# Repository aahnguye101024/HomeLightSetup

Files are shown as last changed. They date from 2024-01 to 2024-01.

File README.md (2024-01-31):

# HomeLightSetup
This project features 2 boards that work together to turn on strips of SK9822 wirelessly and either turn on them using my iphone with shortcuts through wifi or through the main board through a cap touch interface. The main board having an esp32 pico d4 with an antenna for WiFi access, a cap touch ic, and additions to support a lipo battery. The auxiliary board features an esp32 pico d4 with an antenna to communicate with the main board and a hefty 12V to 5V buck to run lights off of.

# Main Board
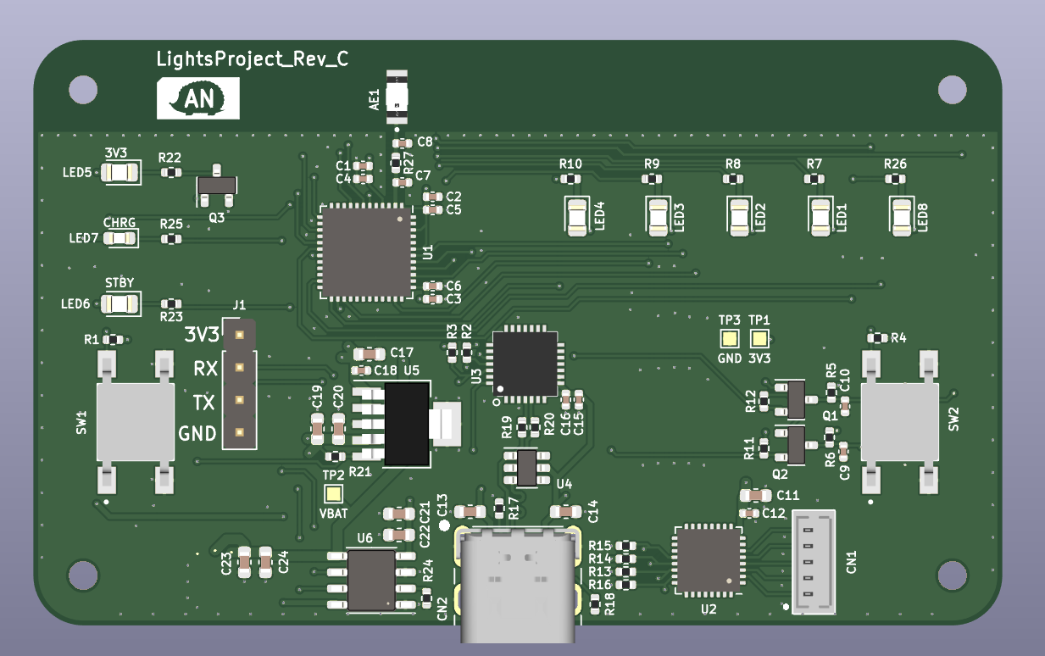
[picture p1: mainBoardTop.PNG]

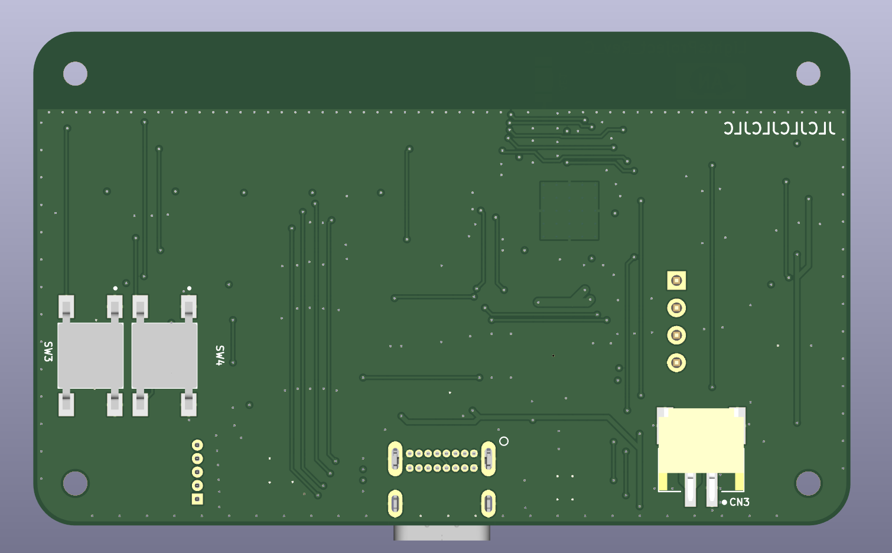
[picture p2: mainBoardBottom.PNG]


# Auxiliary Board
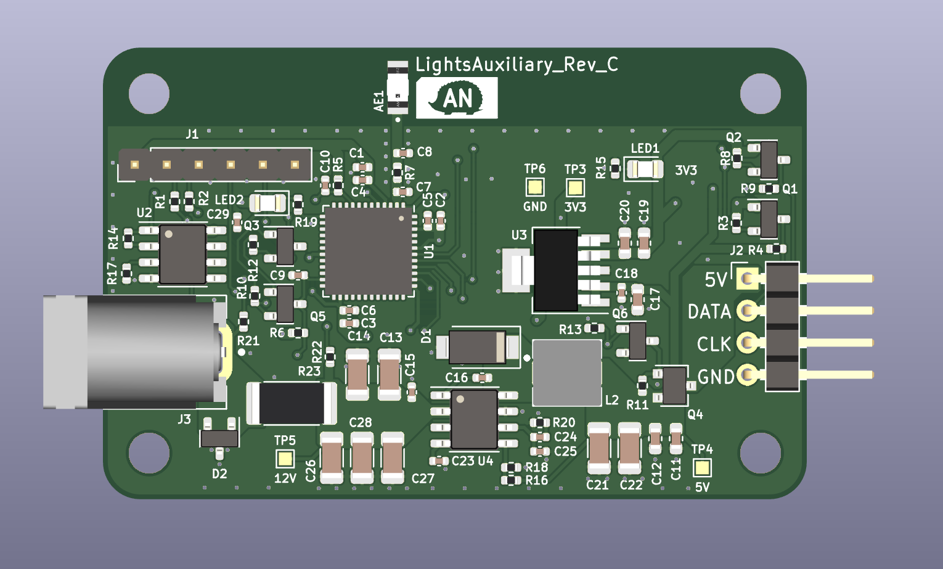
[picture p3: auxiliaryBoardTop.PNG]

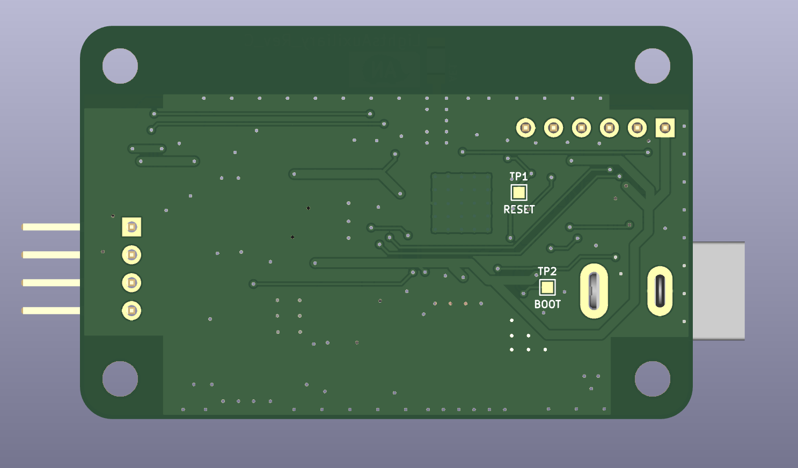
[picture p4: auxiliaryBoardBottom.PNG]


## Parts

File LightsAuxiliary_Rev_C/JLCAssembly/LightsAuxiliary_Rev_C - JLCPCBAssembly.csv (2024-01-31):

Comment | Designator | Footprint | JLCPCB Part #（optional）
2.2uF | C17, C19, C20, | 0603 | C23630
0.1uF | C4, C5, C6, C9, C15, C16, C18, C29, | 0402 | C1525
1uF | C1, C2, C3, C10, | 0402 | C52923
22uF | C13, C14, C26, C27, C28, | 0603 | C59461
47uF | C21, C22, | 1206 | C96123
6.8nF | C23, | 0402 | C1542
4.7nF | C24, | 0402 | C1538
SS54 | D1, | SMA,DO-214AC | C22452
PSM712-LF-T7 | D2, | SOT-23-3 | C32677
SLO0530H6R8MTT | L2, | SMD_5.4x5.2x3mm | C325965
2N7002 | Q1, Q2, Q6, | SOT-23-3 | C8545
MMBT3904 | Q3, Q5, | SOT-23-3 | C20526
AO3401A | Q4, | SOT-23-3L | C15127
0 | R1, R2, R7, | 0402 | C17168
10k | R3, R4, R5, R8, R9, R10, R12, R16, | 0402 | C25744
4.7k | R6, R11, R13, | 0402 | C25900
100k | R14, R17, | 0402 | C25741
330 | R15, R19, | 0402 | C25104
49.9k | R20, | 0402 | C25897
1k | R21, R22, | 0402 | C11702
ESP32-PICO-D4 | U1, | QFN-48_EP_7.0x7.0x0.5P | C193707
LM358DR2G | U2, | SOIC-8_3.9x4.9x1.27P | C7950
TPS54331DR | U4, | SOIC-8_3.9x4.9x1.27P | C9865

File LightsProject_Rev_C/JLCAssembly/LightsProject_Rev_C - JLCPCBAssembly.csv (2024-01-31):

Comment | Designator | Footprint | JLCPCB Part #（optional）
1uF | C1, C2, C3, C10, C15, | 0402 | C52923
0.1uF | C4, C5, C6, C9, C12, C16, C18, | 0402 | C1525
2.2uF | C11, C13, C14, C17, C19, C20, | 0603 | C23630
4.7uF | C21, C22, C23, C24, | 0603 | C19666
19-213/Y2C-CQ2R2L/3T(CY) | LED7, | LED_0603 | C72038
MMBT3904 | Q1, Q2, | SOT-23-3 | C20526
2N7002 | Q3, | SOT-23-3 | C8545
4.7k | R1, R4, R6, R13, R14, R15, R16, | 0402 | C25900
0 | R2, R3, R19, R20, R27, | 0402 | C17168
10k | R5, R11, R12, | 0402 | C25744
330 | R7, R8, R9, R10, R22, R26, | 0402 | C25104
5.1k | R17, R18, | 0402 | C25905
100k | R21, | 0402 | C25741
1.5k | R23, R25, | 0402 | C25867
1.2k | R24, | 0402 | C25862
ESP32-PICO-D4 | U1, | QFN-48_EP_7.0x7.0x0.5P | C193707
CP2102-GMR | U3, | QFN-28_EP_5.0x5.0x0.5P | C6568
SRV05-4-P-T7 | U4, | SOT-23-6L | C85364
TP4056-42-ESOP8 | U6, | ESOP-8_EP_3.9x4.9x1.27P | C16581

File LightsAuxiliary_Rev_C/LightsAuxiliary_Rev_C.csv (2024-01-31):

Source: | C:\Users\AaronN\Desktop\Personal\PersonalProjects\LightsProject\VersionC\LightsAuxiliary_Rev_C\LightsAuxiliary_Rev_C.kicad_sch
Date: | 2/7/2022 12:26:49 AM
Tool: | Eeschema (6.0.0)
Generator: | C:\Program Files\KiCad\bin\scripting\plugins/AaronsFavoriteBOMScript.py
Component Count: | 70
Ref | Qnty | Value | Cmp name | Description | Manufacturer | Part Number
AE1, | 1 | AMCA31-2R450G-S1F-T3 | AMCA31-2R450G-S1F-T3 | RF ANT 2.4GHZ CHIP SOLDER SMD | Abracon LLC | 535-14095-1-ND
C1, C2, C3, C10, | 4 | 1uF | 1uF | CAP CER 1UF 10V X5R 0402 | Samsung Electro-Mechanics | 1276-1076-1-ND
C4, C5, C6, C9, C15, C16, C18, C29, | 8 | 0.1uF | 0.1uF | CAP CER 0.1UF 25V X5R 0402 | Samsung Electro-Mechanics | 1276-1043-1-ND
C11, C12, | 2 | 22uF | 22uF | CAP CER 22UF 10V X5R 0603 | Samsung Electro-Mechanics | 1276-1274-1-ND
C13, C14, C26, C27, C28, | 5 | 22uF_1206 | 22uF_1206 | CAP CER 22UF 25V X5R 1206 | Samsung Electro-Mechanics | 1276-3047-1-ND
C17, C19, C20, | 3 | 2.2uF | 2.2uF | CAP CER 2.2UF 10V X5R 0603 | Samsung Electro-Mechanics | 1276-1085-1-ND
C21, C22, | 2 | 47uF | 47uF | CAP CER 47UF 16V X5R 1206 | Taiyo Yuden | 587-5425-1-ND
C23, | 1 | 6.8nF | 6.8nF | CAP CER 0402 6.8NF 50V X7R 10% | KEMET | 399-C0402C682K5RECAUTOCT-ND
C24, | 1 | 4700pF | 4700pF | CAP CER 4700PF 50V X7R 0402 | YAGEO | 311-1418-1-ND
C25, | 1 | 39pF | 39pF | CAP CER 39PF 50V C0G/NP0 0402 | Murata Electronics | 490-5871-1-ND
D1, | 1 | SS54 | SS54 | JLCPCB 40V 550mV@5A 5A SMA(DO-214AC) Schottky Barrier Diodes (SBD) ROHS | JLCPCB | C22452
D2, | 1 | PSM712-LF-T7 | PSM712-LF-T7 | JLCPCB 19V 13.3V 12V Bi-Directional SOT-23(SOT-23-3) TVS ROHS | JLCPCB | C32677
J1, | 1 | Conn_01x06 | Conn_01x06 | Generic connector, single row, 01x06, script generated (kicad-library-utils/schlib/autogen/connector/)
J2, | 1 | Conn_01x04 | Conn_01x04 | Generic connector, single row, 01x04, script generated (kicad-library-utils/schlib/autogen/connector/)
J3, | 1 | PJ-037AH | PJ-037AH | DC Barrel Jack 2.1mm by 5.50mm R/A | CUI Devices | PJ-037AH
L1, | 1 | LQG15HS2N7S02D | LQG15HS2N7S02D | FIXED IND 2.7NH 800MA 150MOHM SM | Murata Electronics | 490-2615-1-ND
L2, | 1 | SLO0530H6R8MTT | SLO0530H6R8MTT | JLCPCB 4A 6.8uH ±20% 66mΩ SMD Power Inductors ROHS | JLCPCB | C325965
LED1, LED2, | 2 | NCD0805R1 | NCD0805R1 | JLCPCB LED RED DIFFUSED 0805 SMD | Foshan NationStar Optoelectronics | C84256
Q1, Q2, Q6, | 3 | 2N7002 | 2N7002 | JLCPCB MOSFET N-CH 60V 115MA SOT-23 | Changjiang Electronics Tech (CJ) | C8545
Q3, Q5, | 2 | MMBT3904 | MMBT3904 | JLCPCB 0.2W 0.2A NPN 40V SOT-23(SOT-23-3) Bipolar Transistors - BJT ROHS | Changjiang Electronics Tech (CJ) | C20526
Q4, | 1 | AO3401A | AO3401A | JLCPCB 1.4W 0.044Ω 4.3A,10V 30V 1.3V 250uA P Channel 4A SOT-23-3L MOSFETs ROHS | JLCPCB | C15127
R1, R2, R7, | 3 | 0 | 0 | RES 0 OHM JUMPER 1/16W 0402 | Stackpole Electronics Inc | RMCF0402ZT0R00CT-ND
R3, R4, R5, R8, R9, R10, R12, R16, | 8 | 10k | 10k | RES 10K OHM 1% 1/16W 0402 | Stackpole Electronics Inc | RMCF0402FT10K0CT-ND
R6, R11, R13, | 3 | 4.7k | 4.7k | RES 4.7K OHM 1% 1/16W 0402 | Stackpole Electronics Inc | RMCF0402FT4K70CT-ND
R14, R17, | 2 | 100k | 100k | RES SMD 100 KOHM 1% 1/16W 0402 | Delta Electronics/Cyntec | 2037-PFR05S-104-FNHCT-ND
R15, R19, | 2 | 330 | 330 | RES 330 OHM 1% 1/16W 0402 | YAGEO | 311-330LRCT-ND
R18, | 1 | 1.91k | 1.91k | RES 1.91K OHM 1% 1/16W 0402 | Stackpole Electronics Inc | RMCF0402FT1K91CT-ND
R20, | 1 | 49.9k | 49.9k | RES 49.9K OHM 1% 1/16W 0402 | Stackpole Electronics Inc | RMCF0402FT49K9CT-ND
R21, R22, | 2 | 1k | 1k | RES 1K OHM 1% 1/16W 0402 | Stackpole Electronics Inc | RMCF0402FT1K00CT-ND
R23, | 1 | 0.006 | 0.006 | RES 0.006 OHM 1% 1W 2512 | YAGEO | YAG2146CT-ND
U1, | 1 | ESP32-PICO-D4 | ESP32-PICO-D4 |  | Espressif Systems | 1904-1029-1-ND
U2, | 1 | LM358DR2G | LM358DR2G | JLCPCB 0.6 V/us 2 1MHz 3V ~ 32V, ±1.5V ~ 16V 1.5mA General Purpose SOIC-8_150mil Operational Amplifier ROHS | JLCPCB | C7950
U3, | 1 | MCP1826T-3302E_DC | MCP1826T-3302E_DC | IC REG LINEAR 3.3V 1A SOT223-5 | Microchip Technology | Ologic
U4, | 1 | TPS54331DR | TPS54331DR | JLCPCB IC REG BUCK ADJUSTABLE 3A 8SOIC | Texas Instruments | 296-26991-1-ND

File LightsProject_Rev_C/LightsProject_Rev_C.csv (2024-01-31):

Source: | C:\Users\AaronN\Desktop\Personal\PersonalProjects\LightsProject\VersionC\LightsProject_Rev_C\LightsProject_Rev_C.kicad_sch
Date: | 2/7/2022 8:01:38 PM
Tool: | Eeschema (6.0.0)
Generator: | C:\Program Files\KiCad\bin\scripting\plugins/AaronsFavoriteBOMScript.py
Component Count: | 75
Ref | Qnty | Value | Cmp name | Description | Manufacturer | Part Number
AE1, | 1 | AMCA31-2R450G-S1F-T3 | AMCA31-2R450G-S1F-T3 | RF ANT 2.4GHZ CHIP SOLDER SMD | Abracon LLC | 535-14095-1-ND
C1, C2, C3, C10, C15, | 5 | 1uF | 1uF | CAP CER 1UF 10V X5R 0402 | Samsung Electro-Mechanics | 1276-1076-1-ND
C4, C5, C6, C9, C12, C16, C18, | 7 | 0.1uF | 0.1uF | CAP CER 0.1UF 25V X5R 0402 | Samsung Electro-Mechanics | 1276-1043-1-ND
C11, C13, C14, C17, C19, C20, | 6 | 2.2uF | 2.2uF | CAP CER 2.2UF 10V X5R 0603 | Samsung Electro-Mechanics | 1276-1085-1-ND
C21, C22, C23, C24, | 4 | 4.7uF | 4.7uF | CAP CER 4.7UF 16V X5R 0603 | Samsung Electro-Mechanics | 1276-1784-1-ND
CN1, | 1 | 0530470510 | 0530470510 | PICOBLADE VERT CONN HEADER VERT 5POS 1.25MM | Molex | WM1734-ND
CN2, | 1 | 2137160001 | 2137160001 | CONN RCPT USB2.0 TYPE C 24POS RA | Molex | 900-2137160001CT-ND
CN3, | 1 | S2B-PH-SM4-TB(LF)(SN) | S2B-PH-SM4-TB(LF)(SN) | JST PH R/A CONN HEADER SMD R/A 2POS 2MM | JST Sales America Inc. | 455-1749-1-ND
L1, | 1 | LQG15HS2N7S02D | LQG15HS2N7S02D | FIXED IND 2.7NH 800MA 150MOHM SM | Murata Electronics | 490-2615-1-ND
LED1, LED2, LED3, LED4, LED5, LED6, LED8, | 7 | NCD0805R1 | NCD0805R1 | JLCPCB LED RED DIFFUSED 0805 SMD | Foshan NationStar Optoelectronics | C84256
LED7, | 1 | Y2C-CQ2R2L | Y2C-CQ2R2L | JLCPCB LED YELLOW DIFFUSED 0603 SMD | Everlight Elec | C72038
Q1, Q2, | 2 | MMBT3904 | MMBT3904 | JLCPCB 0.2W 0.2A NPN 40V SOT-23(SOT-23-3) Bipolar Transistors - BJT ROHS | Changjiang Electronics Tech (CJ) | C20526
Q3, | 1 | 2N7002 | 2N7002 | JLCPCB MOSFET N-CH 60V 115MA SOT-23 | Changjiang Electronics Tech (CJ) | C8545
R1, R4, R6, R13, R14, R15, R16, | 7 | 4.7k | 4.7k | RES 4.7K OHM 1% 1/16W 0402 | Stackpole Electronics Inc | RMCF0402FT4K70CT-ND
R2, R3, R19, R20, R27, | 5 | 0 | 0 | RES 0 OHM JUMPER 1/16W 0402 | Stackpole Electronics Inc | RMCF0402ZT0R00CT-ND
R5, R11, R12, | 3 | 10k | 10k | RES 10K OHM 1% 1/16W 0402 | Stackpole Electronics Inc | RMCF0402FT10K0CT-ND
R7, R8, R9, R10, R22, R26, | 6 | 330 | 330 | RES 330 OHM 1% 1/16W 0402 | YAGEO | 311-330LRCT-ND
R17, R18, | 2 | 5.1k | 5.1k | RES 5.1K OHM 1% 1/16W 0402 | YAGEO | 311-5.10KLRCT-ND
R21, | 1 | 100k | 100k | RES SMD 100 KOHM 1% 1/16W 0402 | Delta Electronics/Cyntec | 2037-PFR05S-104-FNHCT-ND
R23, R25, | 2 | 1.5k | 1.5k | RES 1.5K OHM 1% 1/16W 0402 | Stackpole Electronics Inc | RMCF0402FT1K50CT-ND
R24, | 1 | 1.2k | 1.2k | RES SMD 1.2K OHM 1% 1/16W 0402 | YAGEO | YAG3447CT-ND
SW1, SW2, SW3, SW4, | 4 | FSM2JSMAA | FSM2JSMAA | SMD Momentary PushButton | FSM2JSMAA | 450-3355-ND
U1, | 1 | ESP32-PICO-D4 | ESP32-PICO-D4 |  | Espressif Systems | 1904-1029-1-ND
U2, | 1 | CAP1114-1-EZK-TR | CAP1114-1-EZK-TR | IC TOUCH SENSOR/LED DRVR 32VQFN | Ologic | Ologic
U3, | 1 | CP2102-GMR | CP2102-GMR | JLCPCB IC USB-TO-UART BRIDGE 28VQFN | CP2102-GMR | IC USB-TO-UART BRIDGE 28VQFN
U4, | 1 | SRV05-4-P-T7 | SRV05-4-P-T7 | JLCPCB 1A@80/20μs 12V 6V 5V SOT-23-6 TVS ROHS | JLCPCB | C85364
U5, | 1 | MCP1826T-3302E_DC | MCP1826T-3302E_DC | IC REG LINEAR 3.3V 1A SOT223-5 | Microchip Technology | Ologic
U6, | 1 | TP4056-42-ESOP8 | TP4056-42-ESOP8 | JLCPCB 1 Li-Ion Charger ESOP-8 Battery Management ICs ROHS | JLCPCB | C16581

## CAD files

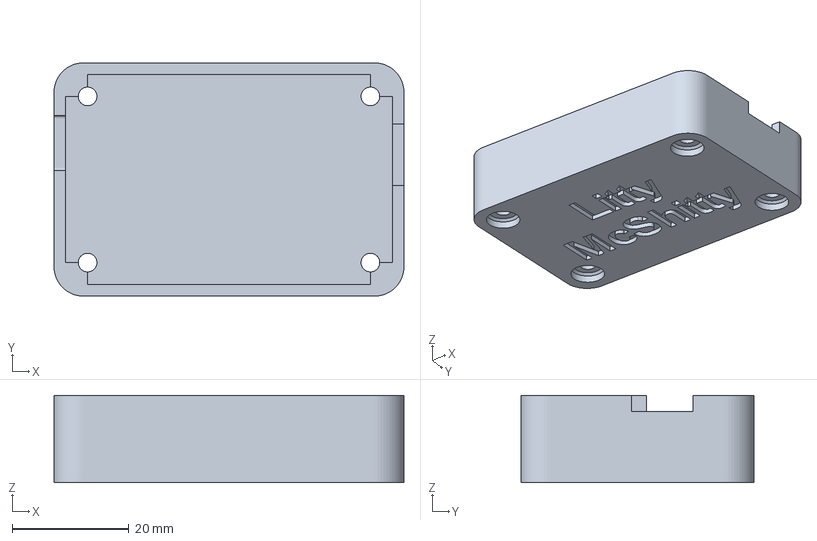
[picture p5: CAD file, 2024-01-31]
LightsAuxiliary_Rev_C/3DCase/TopCase v3.3mf
60.0 x 40.0 x 15.0 mm

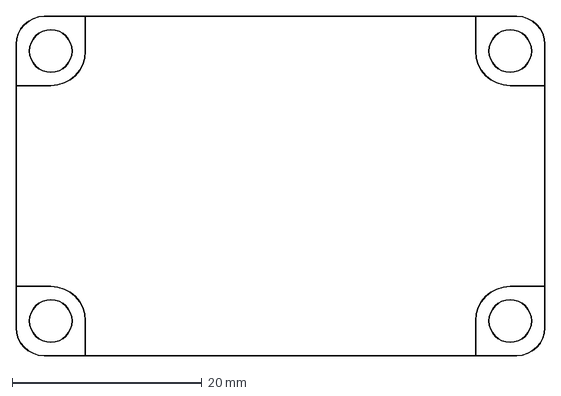
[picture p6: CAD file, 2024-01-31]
LightsAuxiliary_Rev_C/BoardOutline.dxf
55.8 x 35.8 mm

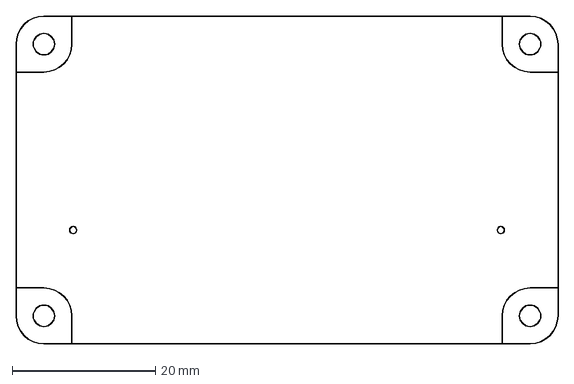
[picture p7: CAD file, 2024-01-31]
LightsProject_Rev_C/BoardOutline.dxf
75.8 x 45.8 mm

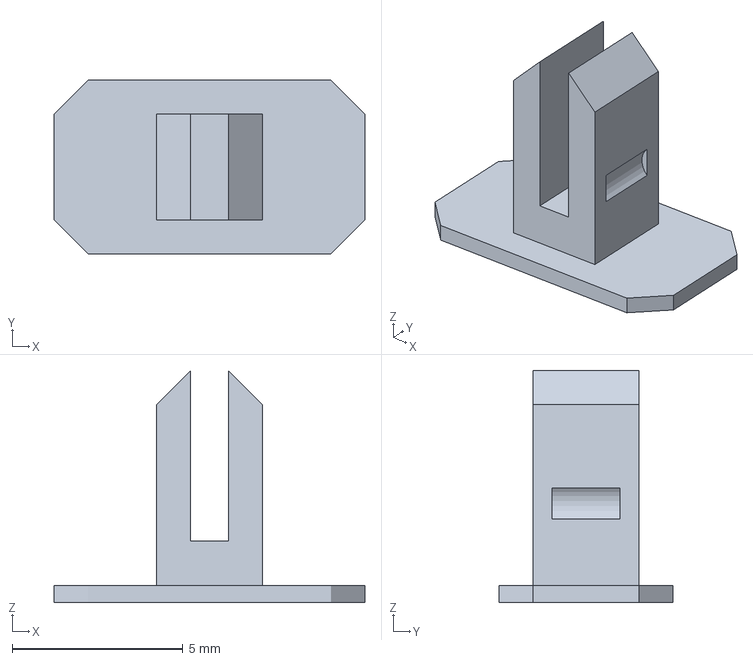
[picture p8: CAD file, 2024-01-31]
LightsProject_Rev_C/CaseSteps/ButtonExtender v2.3mf
9.10 x 5.10 x 6.80 mm

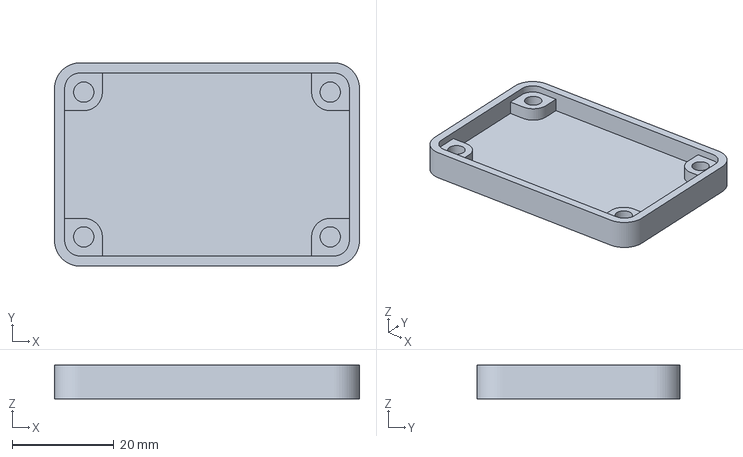
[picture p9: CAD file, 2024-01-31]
LightsAuxiliary_Rev_C/3DCase/BottomCase v3.3mf
60.0 x 40.0 x 6.60 mm

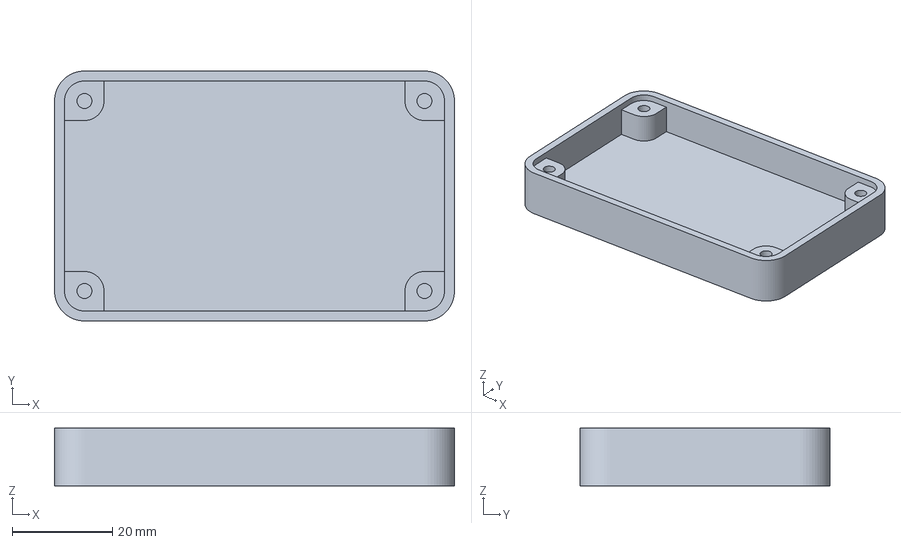
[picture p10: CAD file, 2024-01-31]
LightsProject_Rev_C/CaseSteps/BottomCase v10.3mf
80.0 x 50.0 x 11.6 mm

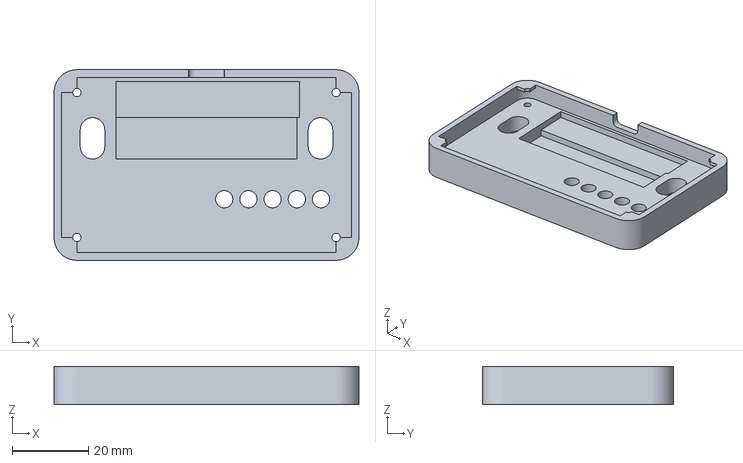
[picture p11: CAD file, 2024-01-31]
LightsProject_Rev_C/CaseSteps/TopCase v4.3mf
80.0 x 50.0 x 10.0 mm

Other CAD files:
LightsAuxiliary_Rev_C/3DCase/BottomCase v3.stl
LightsAuxiliary_Rev_C/3DCase/TopCase v3.stl
LightsProject_Rev_C/CaseSteps/BottomCase v10.stl
LightsProject_Rev_C/CaseSteps/ButtonExtender v2.stl
LightsProject_Rev_C/CaseSteps/TopCase v4.stl

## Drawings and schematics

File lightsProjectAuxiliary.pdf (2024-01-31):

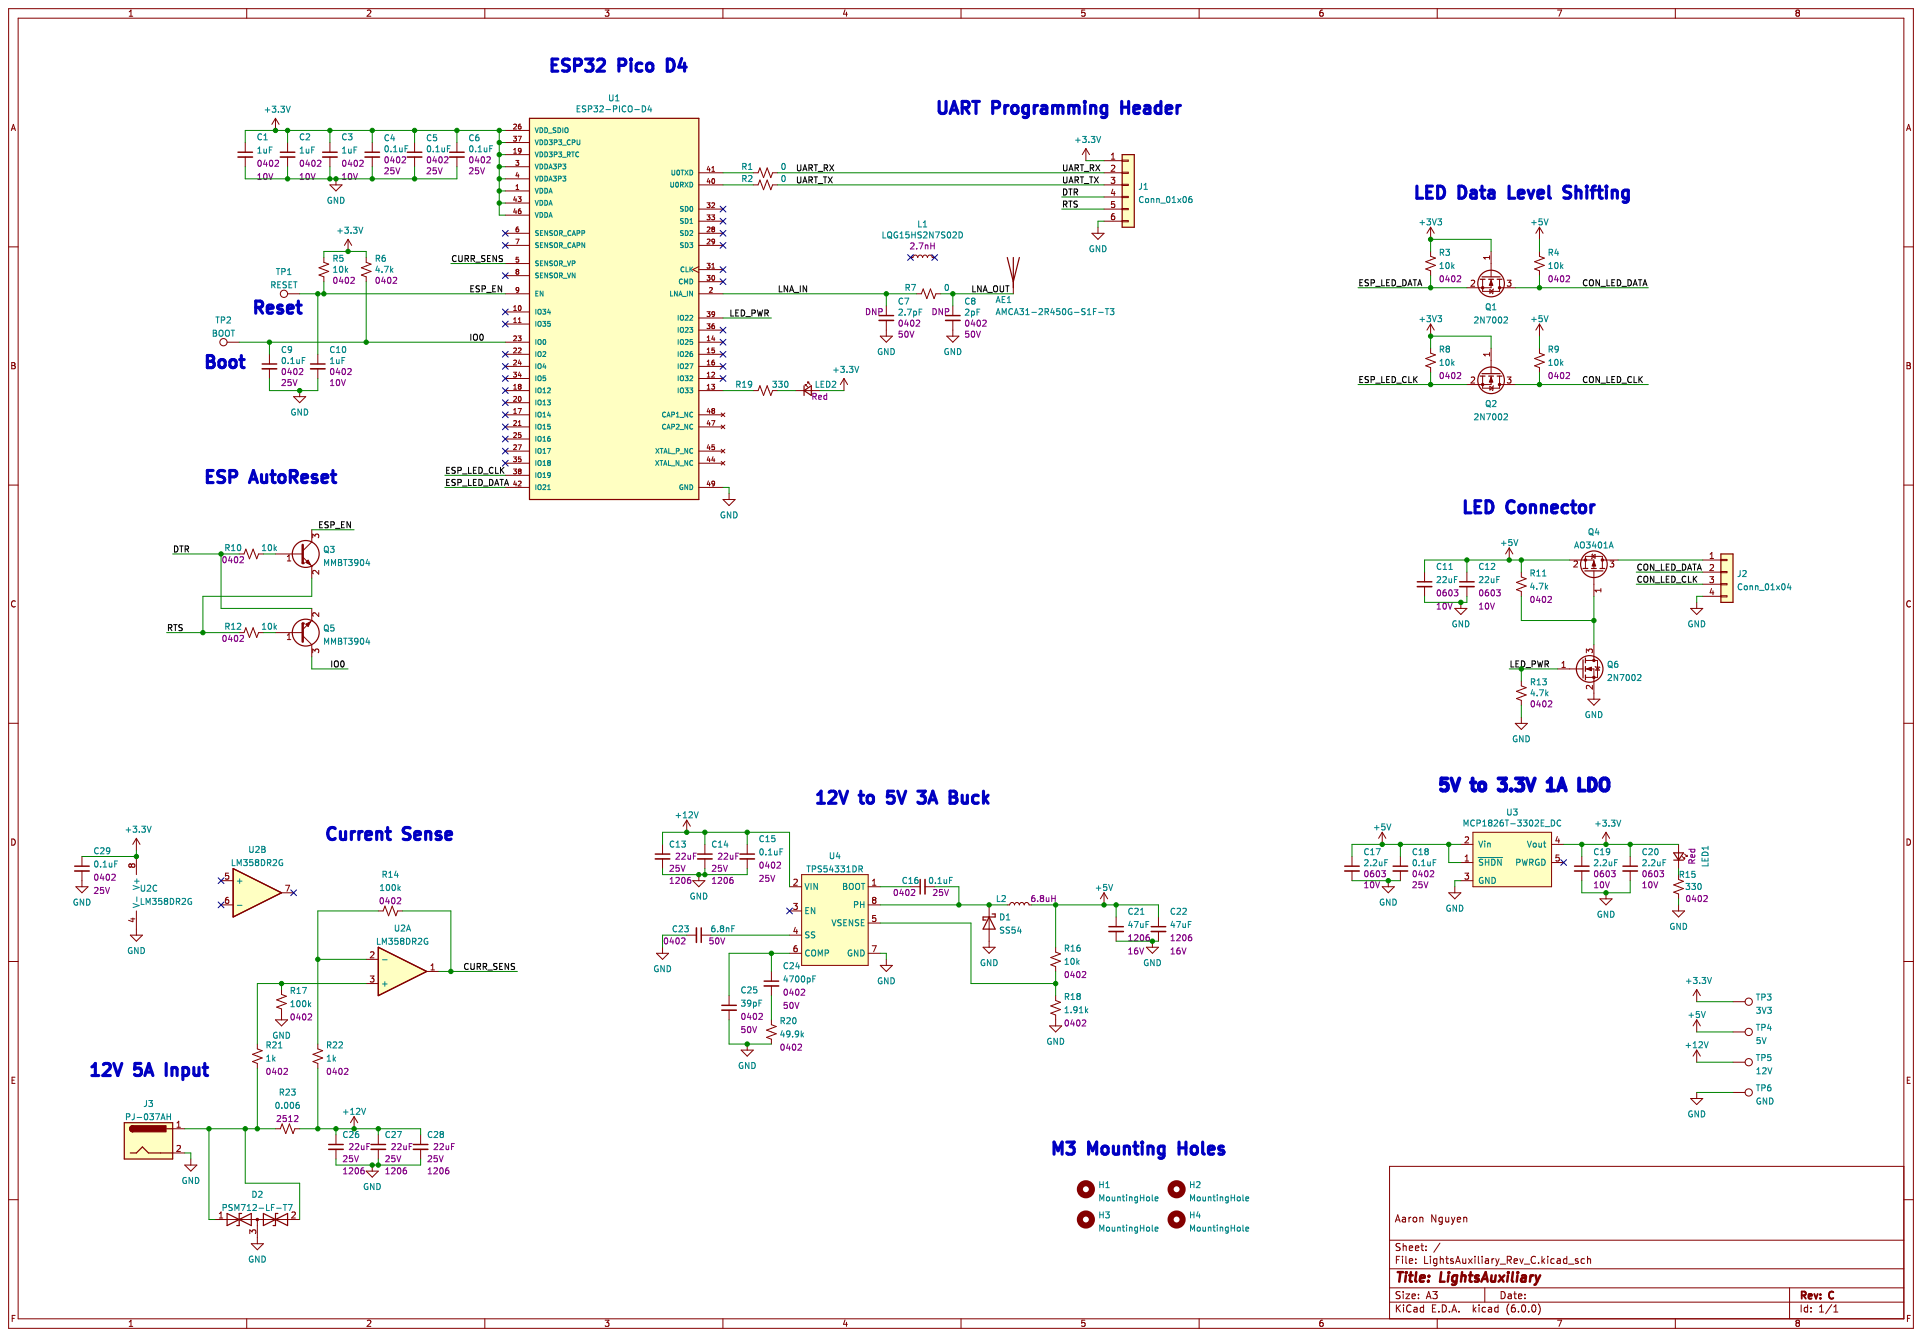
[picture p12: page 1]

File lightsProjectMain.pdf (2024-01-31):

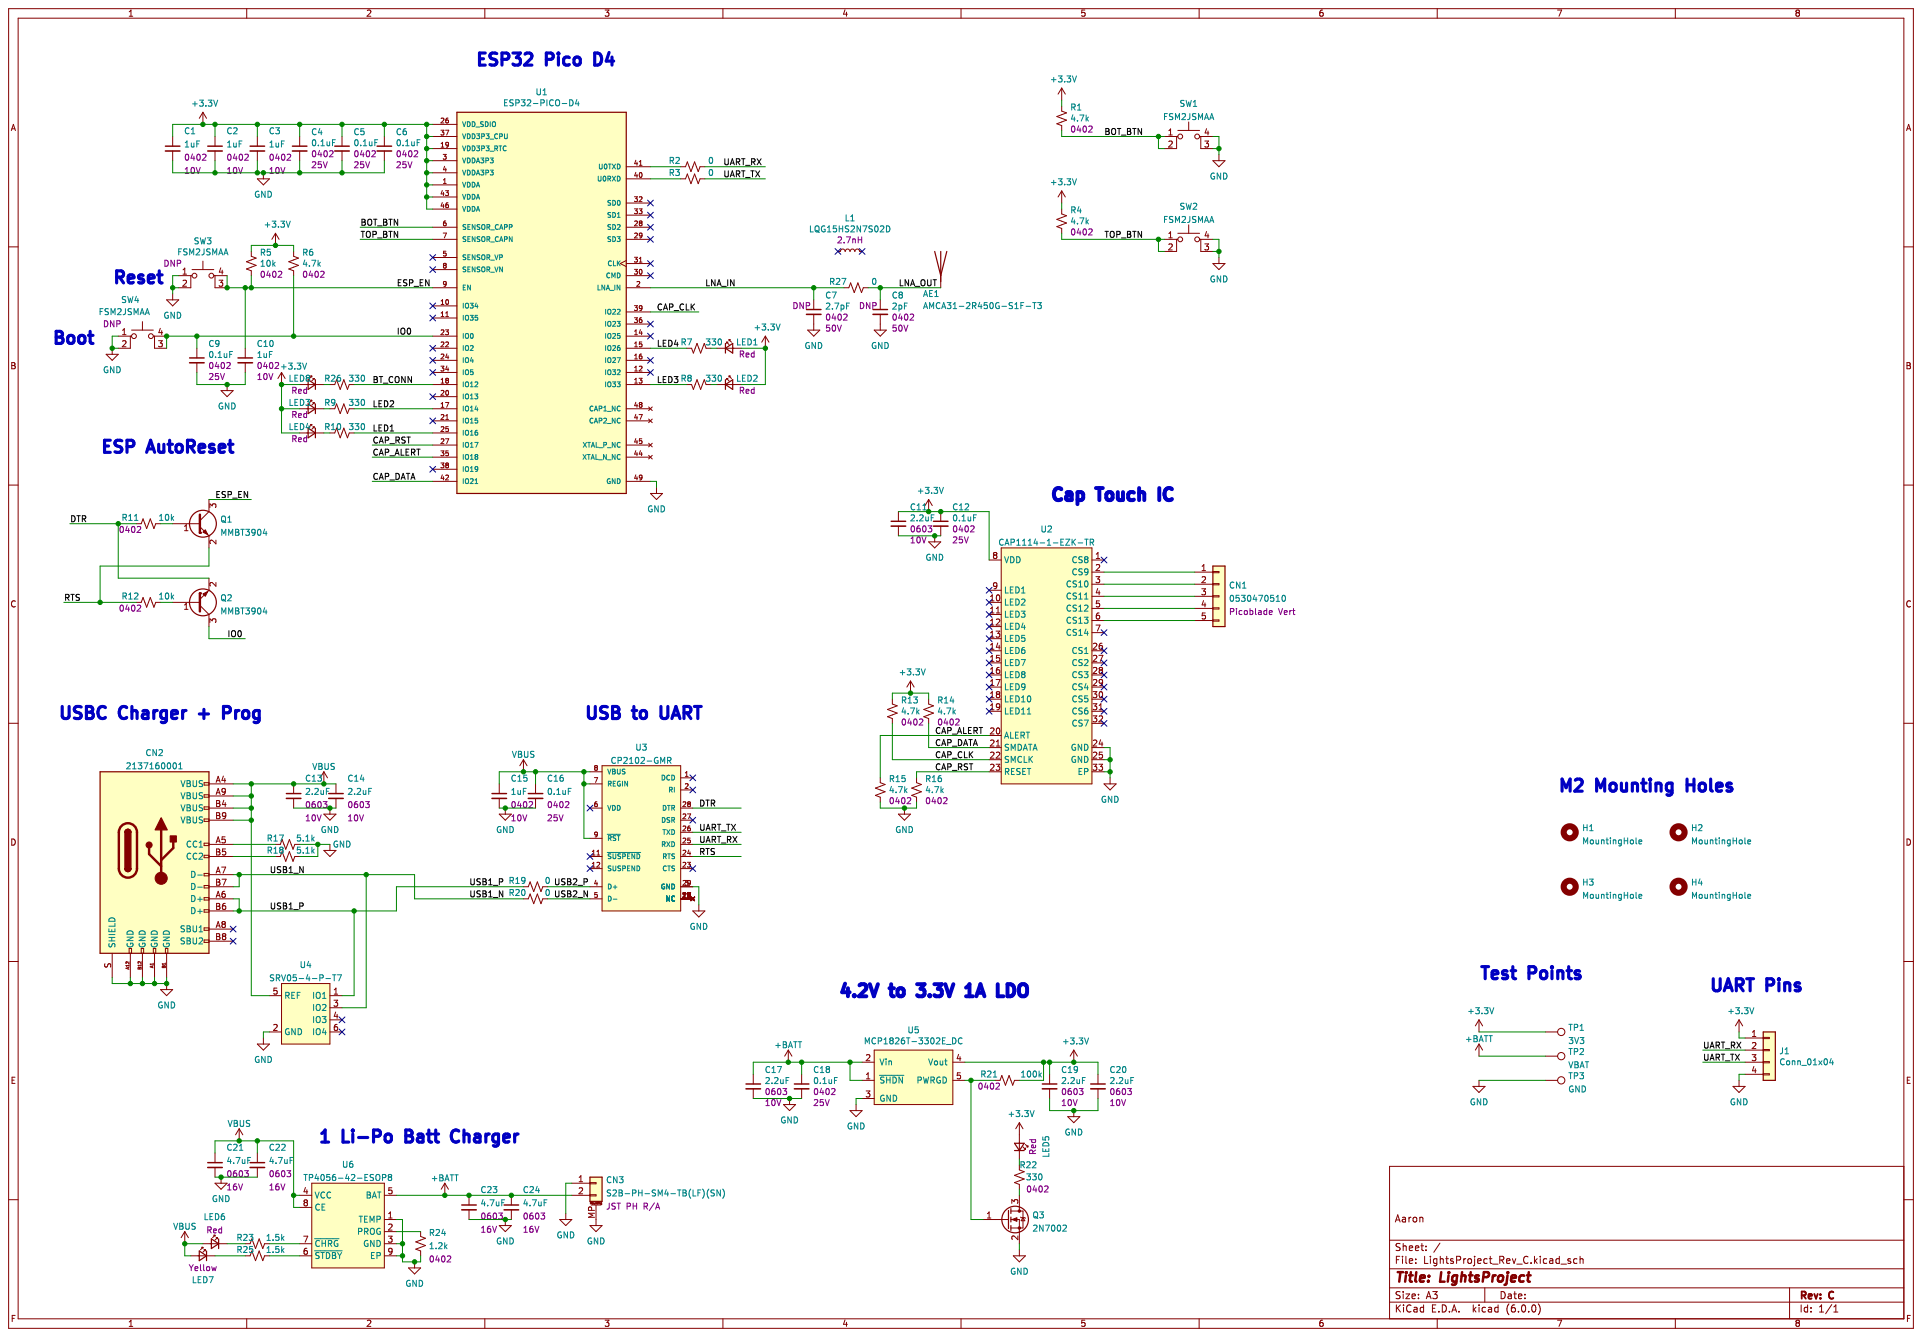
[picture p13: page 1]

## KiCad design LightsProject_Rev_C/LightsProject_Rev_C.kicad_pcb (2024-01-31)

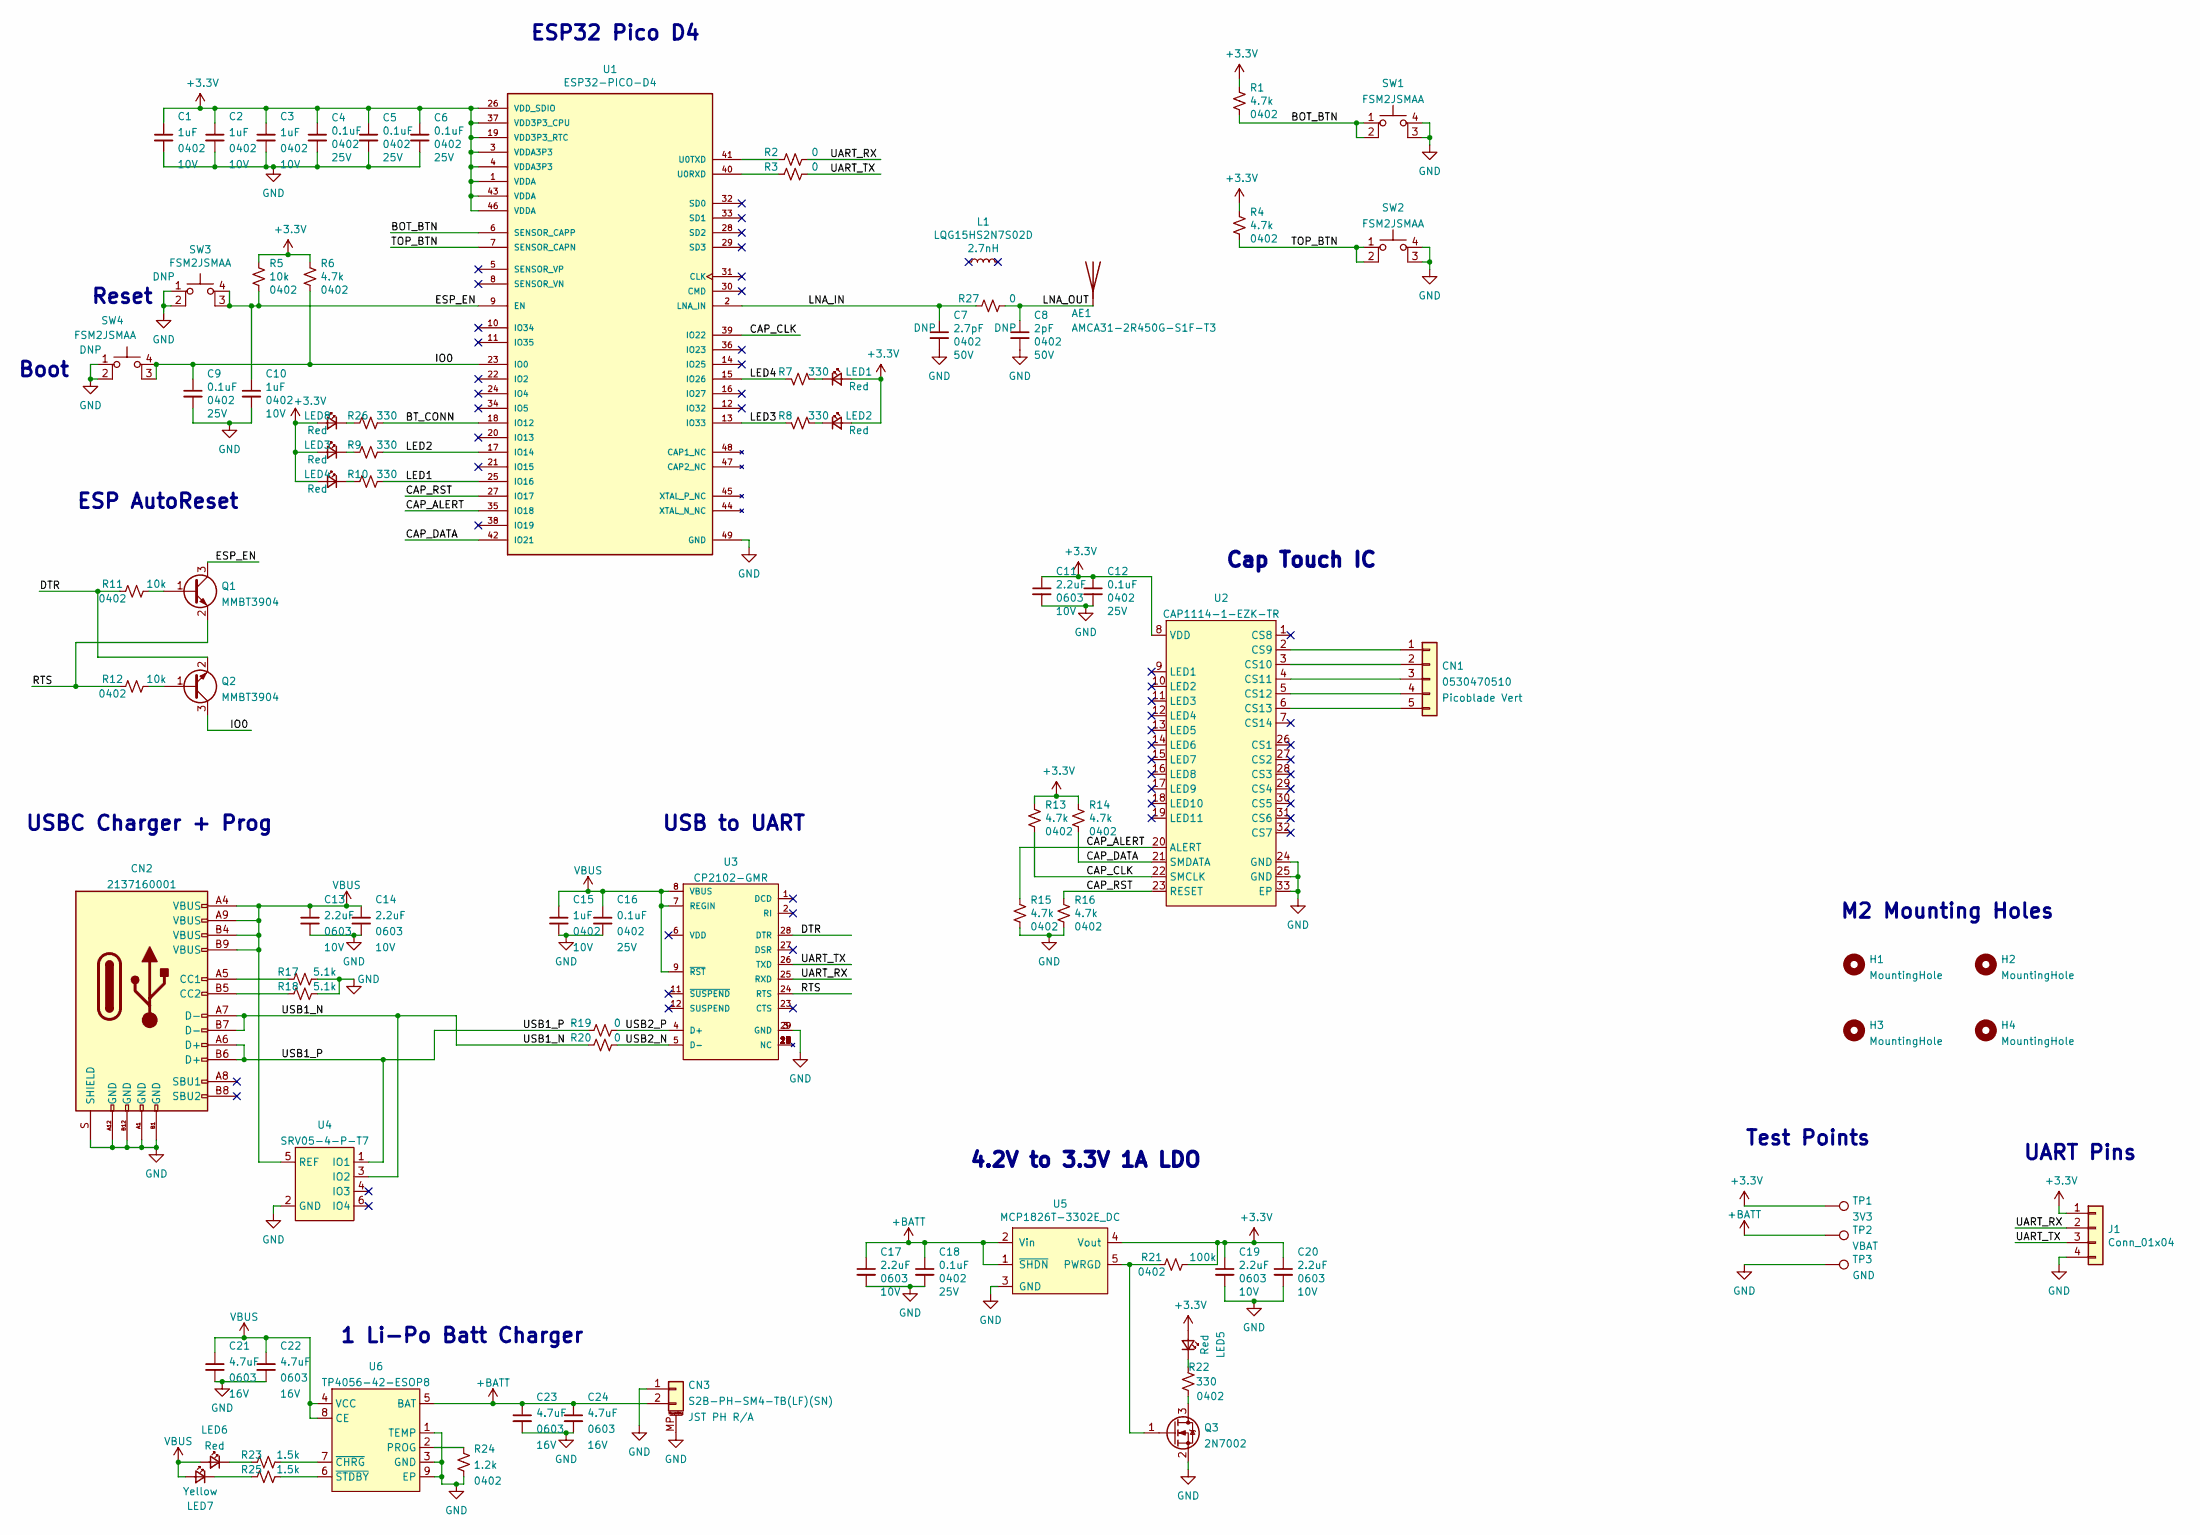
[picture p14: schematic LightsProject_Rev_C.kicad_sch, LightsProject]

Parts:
AE1: AMCA31-2R450G-S1F-T3; ANT_AMCA31-2R450G-S1F-T3; Part Number 535-14095-1-ND
C1, C2, C3, C10, C15: 1uF; C_0402_1005Metric; Voltage 10V; Part Number 1276-1076-1-ND
C4, C5, C6, C9, C12, C16, C18: 0.1uF; C_0402_1005Metric; Voltage 25V; Part Number 1276-1043-1-ND
C7: 2.7pF; C_0402_1005Metric; Voltage 50V; Part Number 311-1005-1-ND
C8: 2pF; C_0402_1005Metric; Voltage 50V; Part Number 311-1006-1-ND
C11, C13, C14, C17, C19, C20: 2.2uF; C_0603_1608Metric; Voltage 10V; Part Number 1276-1085-1-ND
C21, C22, C23, C24: 4.7uF; C_0603_1608Metric; Voltage 16V; Part Number 1276-1784-1-ND
CN1: 0530470510; Part Number WM1734-ND
CN2: 2137160001; Part Number 900-2137160001CT-ND
CN3: S2B-PH-SM4-TB(LF)(SN); JST_S2B-PH-SM4-TB(LF)(SN); Part Number 455-1749-1-ND
H1, H2, H3, H4: MountingHole; MountingHole_2.2mm_M2_ISO14580
J1: Conn_01x04; PinHeader_1x04_P2.54mm_Vertical
L1: LQG15HS2N7S02D; L_0402_1005Metric; Part Number 490-2615-1-ND
LED1, LED2, LED3, LED4, LED5, LED6, LED8: NCD0805R1; LED_0805_2012Metric; Part Number C84256
LED7: Y2C-CQ2R2L; LED_0603_1608Metric; Voltage 2.1V; Part Number C72038
Q1, Q2: MMBT3904; SOT-23; Part Number C20526
Q3: 2N7002; SOT-23; Part Number C8545; JLC Part Number C8545
R1, R4, R6, R13, R14, R15, R16: 4.7k; R_0402_1005Metric; Part Number RMCF0402FT4K70CT-ND
R2, R3, R19, R20, R27: 0; R_0402_1005Metric; Part Number RMCF0402ZT0R00CT-ND
R5, R11, R12: 10k; R_0402_1005Metric; Part Number RMCF0402FT10K0CT-ND
R7, R8, R9, R10, R22, R26: 330; R_0402_1005Metric; Part Number 311-330LRCT-ND
R17, R18: 5.1k; R_0402_1005Metric; Part Number 311-5.10KLRCT-ND
R21: 100k; R_0402_1005Metric; Part Number 2037-PFR05S-104-FNHCT-ND
R23, R25: 1.5k; R_0402_1005Metric; Part Number RMCF0402FT1K50CT-ND
R24: 1.2k; R_0402_1005Metric; Part Number YAG3447CT-ND
SW1, SW2, SW3, SW4: FSM2JSMAA; SW_2-1437565-8; Part Number 450-3355-ND
TP1: 3V3; CurrentTestPoint
TP2: VBAT; CurrentTestPoint
TP3: GND; CurrentTestPoint
U1: ESP32-PICO-D4; QFN-48-1EP_7x7mm_P0.5mm_EP5.3x5.3mm_ThermalVias; Part Number 1904-1029-1-ND
U2: CAP1114-1-EZK-TR; QFN-32-1EP_5x5mm_P0.5mm_EP3.1x3.1mm; Part Number Ologic
U3: CP2102-GMR; QFN28G_0.5-5X5MM; Part Number IC USB-TO-UART BRIDGE 28VQFN; JLC Part Number C6568
U4: SRV05-4-P-T7; SOT-23-6; Part Number C85364
U5: MCP1826T-3302E_DC; SOT-223-6_TabPin3; Part Number Ologic
U6: TP4056-42-ESOP8; HTSOP-8-1EP_3.9x4.9mm_P1.27mm_EP2.4x3.2mm; Part Number C16581

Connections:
+3V3: C1.1, C2.1, C3.1, C4.1, C5.1, C6.1, C11.1, C12.1, C19.1, C20.1, J1.1, LED1.2 (A), LED2.2 (A), LED3.2 (A), LED4.2 (A), LED5.2 (A), LED8.2 (A), R1.1, R4.1, R5.1, R6.1, R13.1, R14.1, R21.2, TP1.1, U1.1 (VDDA), U1.3 (VDDA3P3), U1.4 (VDDA3P3), U1.19 (VDD3P3_RTC), U1.26 (VDD_SDIO), U1.37 (VDD3P3_CPU), U1.43 (VDDA), U1.46 (VDDA), U2.8 (VDD), U5.4 (Vout)
+BATT: C17.1, C18.1, C23.1, C24.1, CN3.2, TP2.1, U5.1 (~SHDN), U5.2 (Vin), U6.5 (BAT)
/BOT_BTN: R1.2, SW1.1, SW1.2, U1.6 (SENSOR_CAPP)
/BT_CONN: R26.1, U1.18 (IO12)
/CAP_ALERT: R15.1, U1.35 (IO18), U2.20 (ALERT)
/CAP_CLK: R13.2, U1.39 (IO22), U2.22 (SMCLK)
/CAP_DATA: R14.2, U1.42 (IO21), U2.21 (SMDATA)
/CAP_RST: R16.1, U1.27 (IO17), U2.23 (RESET)
/DTR: Q2.2 (E), R11.2, U3.28 (DTR)
/ESP_EN: C10.1, Q1.3 (C), R5.2, SW3.3 (K), SW3.4 (A), U1.9 (EN)
/IO0: C9.1, Q2.3 (C), R6.2, SW4.3 (K), SW4.4 (A), U1.23 (IO0)
/LED1: R10.1, U1.25 (IO16)
/LED2: R9.1, U1.17 (IO14)
/LED3: R8.1, U1.13 (IO33)
/LED4: R7.1, U1.15 (IO26)
/LNA_IN: C7.1, R27.2, U1.2 (LNA_IN)
/LNA_OUT: AE1.1 (A), C8.1, R27.1
/RTS: Q1.2 (E), R12.2, U3.24 (RTS)
/TOP_BTN: R4.2, SW2.1, SW2.2, U1.7 (SENSOR_CAPN)
/UART_RX: J1.2, R2.1, U3.25 (RXD)
/UART_TX: J1.3, R3.1, U3.26 (TXD)
/USB1_N: CN2.A7 (D-), CN2.B7 (D-), R20.1, U4.3 (IO2)
/USB1_P: CN2.A6 (D+), CN2.B6 (D+), R19.1, U4.1 (IO1)
/USB2_N: R20.2, U3.5 (D-)
/USB2_P: R19.2, U3.4 (D+)
GND: C1.2, C2.2, C3.2, C4.2, C5.2, C6.2, C7.2, C8.2, C9.2, C10.2, C11.2, C12.2, C13.2, C14.2, C15.2, C16.2, C17.2, C18.2, C19.2, C20.2, C21.2, C22.2, C23.2, C24.2, CN2.A1 (GND), CN2.A12 (GND), CN2.B1 (GND), CN2.B12 (GND), CN2.S (SHIELD), CN3.1, CN3.MP (MountPin), J1.4, Q3.2 (S), R15.2, R16.2, R17.2, R18.2, R24.2, SW1.3 (K), SW1.4 (A), SW2.3 (K), SW2.4 (A), SW3.1, SW3.2, SW4.1, SW4.2, TP3.1, U1.49 (GND), U2.24 (GND), U2.25 (GND), U2.33 (EP), U3.3 (GND), U3.29 (GND), U4.2 (GND), U5.3 (GND), U6.1 (TEMP), U6.3 (GND), U6.9 (EP)
unnamed: CN1.1, U2.2 (CS9)
unnamed: CN1.2, U2.3 (CS10)
unnamed: CN1.3, U2.4 (CS11)
unnamed: CN1.4, U2.5 (CS12)
unnamed: CN1.5, U2.6 (CS13)
unnamed: CN2.A5 (CC1), R17.1
unnamed: CN2.B5 (CC2), R18.1
unnamed: LED1.1 (K), R7.2
unnamed: LED2.1 (K), R8.2
unnamed: LED3.1 (K), R9.2
unnamed: LED4.1 (K), R10.2
unnamed: LED5.1 (K), R22.2
unnamed: LED6.1 (K), R23.1
unnamed: LED7.1 (K), R25.1
unnamed: LED8.1 (K), R26.2
unnamed: Q1.1 (B), R11.1
unnamed: Q2.1 (B), R12.1
unnamed: Q3.1 (G), R21.1, U5.5 (PWRGD)
unnamed: Q3.3 (D), R22.1
unnamed: R2.2, U1.41 (U0TXD)
unnamed: R3.2, U1.40 (U0RXD)
unnamed: R23.2, U6.7 (~CHRG)
unnamed: R24.1, U6.2 (PROG)
unnamed: R25.2, U6.6 (~STDBY)
VBUS: C13.1, C14.1, C15.1, C16.1, C21.1, C22.1, CN2.A4 (VBUS), CN2.A9 (VBUS), CN2.B4 (VBUS), CN2.B9 (VBUS), LED6.2 (A), LED7.2 (A), U3.7 (REGIN), U3.8 (VBUS), U3.9 (~RST), U4.5 (REF), U6.4 (VCC), U6.8 (CE)

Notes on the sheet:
1 Li-Po Batt Charger
ESP32 Pico D4
UART Pins
USBC Charger + Prog
Test Points
M2 Mounting Holes
ESP AutoReset
Reset
USB to UART
Cap Touch IC
Boot
4.2V to 3.3V 1A LDO

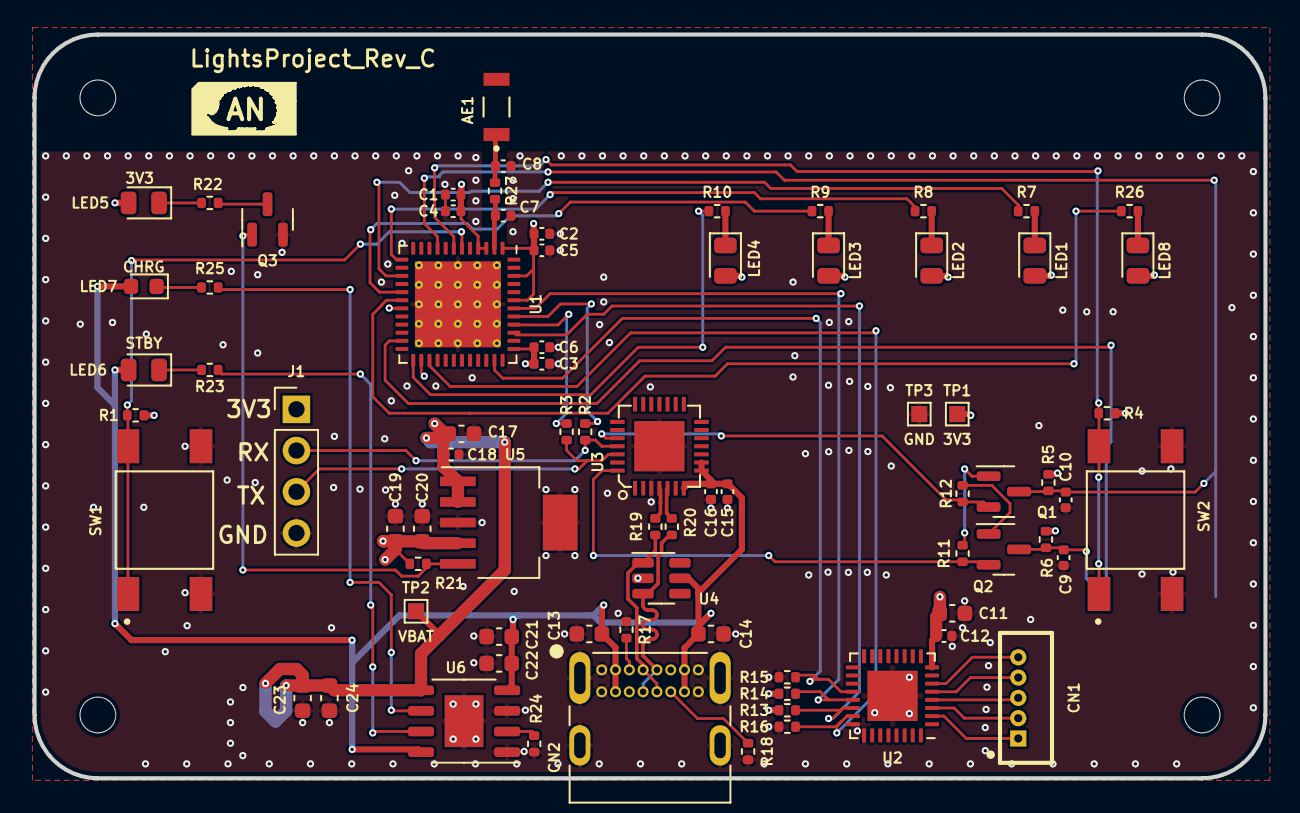
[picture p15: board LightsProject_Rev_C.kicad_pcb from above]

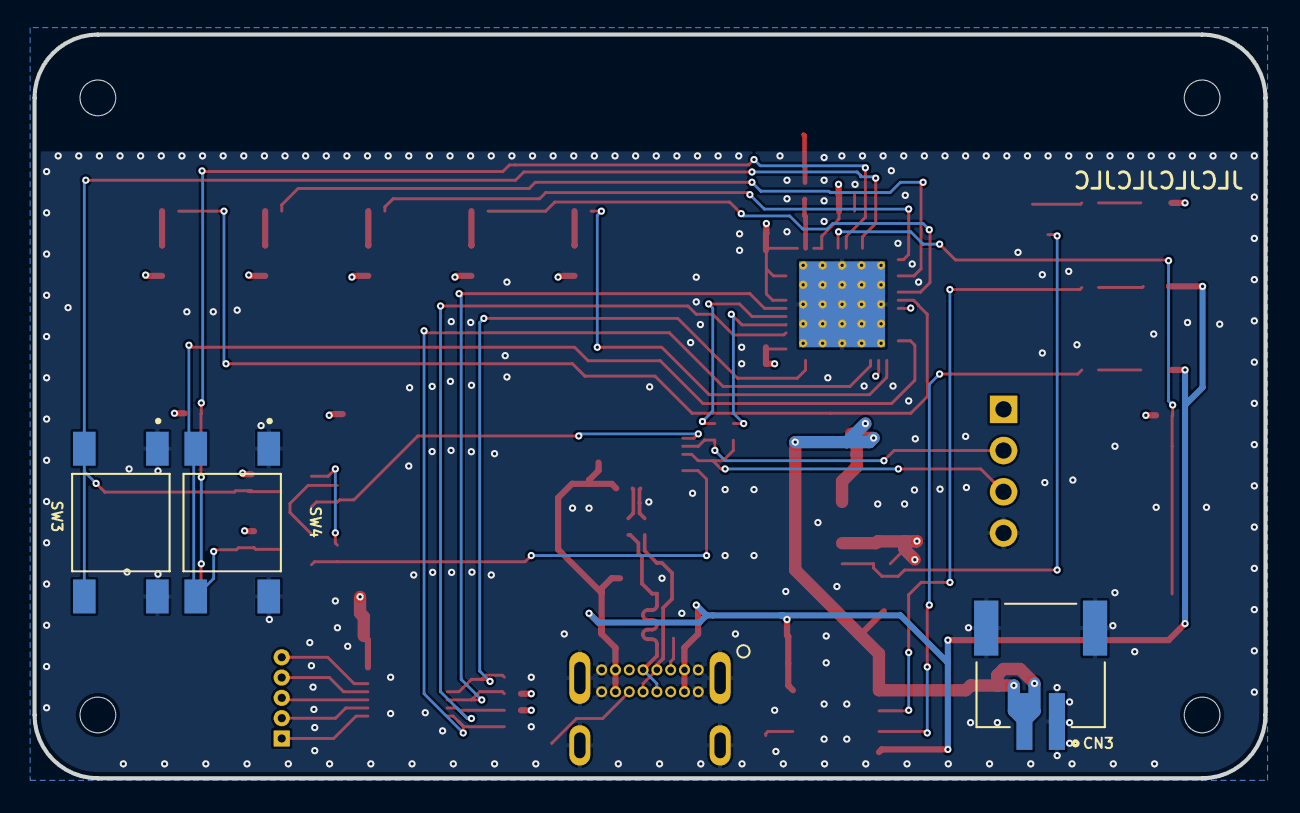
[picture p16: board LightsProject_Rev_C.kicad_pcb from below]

Board: 4 copper layers, 75.8 x 45.8 mm, 84 parts (3 on the bottom side), 51 nets.

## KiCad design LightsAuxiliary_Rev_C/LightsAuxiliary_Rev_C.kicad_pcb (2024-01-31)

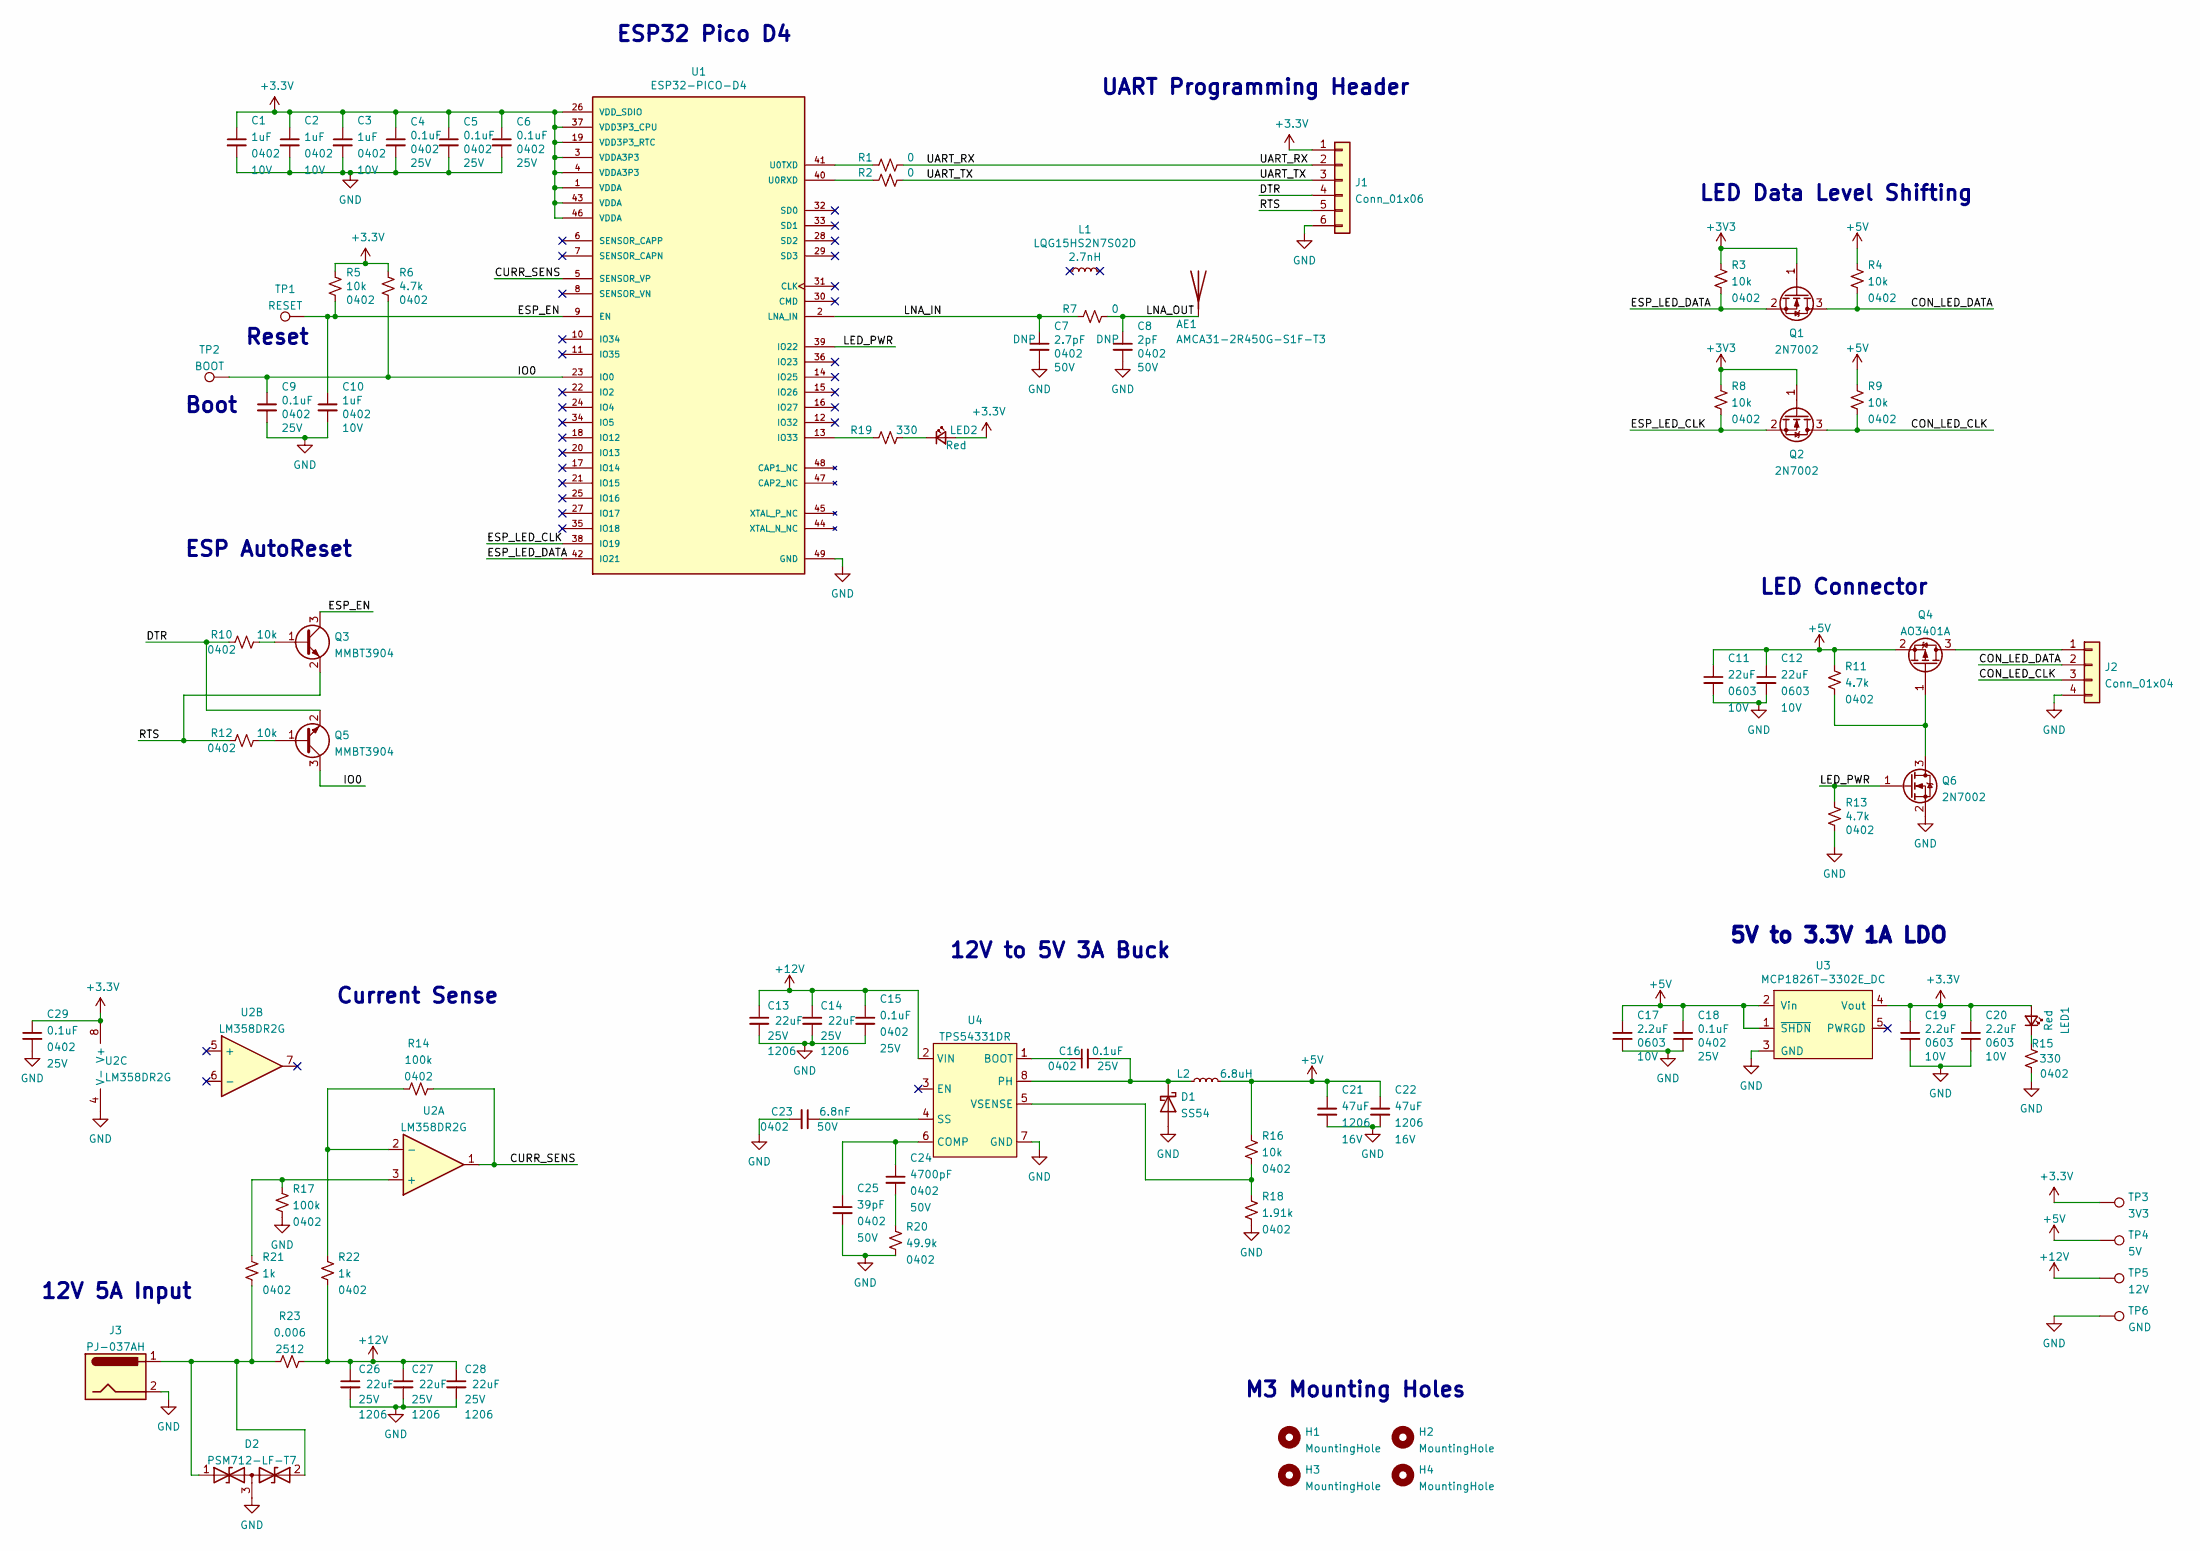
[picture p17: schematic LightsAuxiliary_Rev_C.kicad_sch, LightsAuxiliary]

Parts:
AE1: AMCA31-2R450G-S1F-T3; ANT_AMCA31-2R450G-S1F-T3; Part Number 535-14095-1-ND
C1, C2, C3, C10: 1uF; C_0402_1005Metric; Voltage 10V; Part Number 1276-1076-1-ND
C4, C5, C6, C9, C15, C16, C18, C29: 0.1uF; C_0402_1005Metric; Voltage 25V; Part Number 1276-1043-1-ND
C7: 2.7pF; C_0402_1005Metric; Voltage 50V; Part Number 311-1005-1-ND
C8: 2pF; C_0402_1005Metric; Voltage 50V; Part Number 311-1006-1-ND
C11, C12: 22uF; C_0603_1608Metric; Voltage 10V; Part Number 1276-1274-1-ND
C13, C14, C26, C27, C28: 22uF_1206; C_1206_3216Metric; Voltage 25V; Part Number 1276-3047-1-ND
C17, C19, C20: 2.2uF; C_0603_1608Metric; Voltage 10V; Part Number 1276-1085-1-ND
C21, C22: 47uF; C_1206_3216Metric; Voltage 16V; Part Number 587-5425-1-ND
C23: 6.8nF; C_0402_1005Metric; Voltage 50V; Part Number 399-C0402C682K5RECAUTOCT-ND
C24: 4700pF; C_0402_1005Metric; Voltage 50V; Part Number 311-1418-1-ND
C25: 39pF; C_0402_1005Metric; Voltage 50V; Part Number 490-5871-1-ND
D1: SS54; D_SMA; Part Number C22452
D2: PSM712-LF-T7; SOT-23; Part Number C32677
H1, H2, H3, H4: MountingHole; MountingHole_3.2mm_M3_ISO7380
J1: Conn_01x06; PinHeader_1x06_P2.54mm_Vertical
J2: Conn_01x04; PinHeader_1x04_P2.54mm_Horizontal
J3: PJ-037AH; CUI_PJ-037AH; Part Number PJ-037AH
L1: LQG15HS2N7S02D; L_0402_1005Metric; Part Number 490-2615-1-ND
L2: SLO0530H6R8MTT; Part Number C325965
LED1, LED2: NCD0805R1; LED_0805_2012Metric; Part Number C84256
Q1, Q2, Q6: 2N7002; SOT-23; Part Number C8545; JLC Part Number C8545
Q3, Q5: MMBT3904; SOT-23; Part Number C20526
Q4: AO3401A; SOT-23W; Part Number C15127; JLC Part Number C15127
R1, R2, R7: 0; R_0402_1005Metric; Part Number RMCF0402ZT0R00CT-ND
R3, R4, R5, R8, R9, R10, R12, R16: 10k; R_0402_1005Metric; Part Number RMCF0402FT10K0CT-ND
R6, R11, R13: 4.7k; R_0402_1005Metric; Part Number RMCF0402FT4K70CT-ND
R14, R17: 100k; R_0402_1005Metric; Part Number 2037-PFR05S-104-FNHCT-ND
R15, R19: 330; R_0402_1005Metric; Part Number 311-330LRCT-ND
R18: 1.91k; R_0402_1005Metric; Part Number RMCF0402FT1K91CT-ND
R20: 49.9k; R_0402_1005Metric; Part Number RMCF0402FT49K9CT-ND
R21, R22: 1k; R_0402_1005Metric; Part Number RMCF0402FT1K00CT-ND
R23: 0.006; R_2512_6332Metric; Part Number YAG2146CT-ND
TP1: RESET; CurrentTestPoint
TP2: BOOT; CurrentTestPoint
TP3: 3V3; CurrentTestPoint
TP4: 5V; CurrentTestPoint
TP5: 12V; CurrentTestPoint
TP6: GND; CurrentTestPoint
U1: ESP32-PICO-D4; QFN-48-1EP_7x7mm_P0.5mm_EP5.3x5.3mm_ThermalVias; Part Number 1904-1029-1-ND
U2: LM358DR2G; SOIC-8_3.9x4.9mm_P1.27mm; Part Number C7950
U3: MCP1826T-3302E_DC; SOT-223-6_TabPin3; Part Number Ologic
U4: TPS54331DR; SOIC-8_3.9x4.9mm_P1.27mm; Part Number 296-26991-1-ND

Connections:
+5V: C11.1, C12.1, C17.1, C18.1, C21.1, C22.1, L2.2, Q4.2 (S), R4.1, R9.1, R11.1, R16.1, TP4.1, U3.1 (~SHDN), U3.2 (Vin)
+12V: C13.1, C14.1, C15.1, C26.1, C27.1, C28.1, R22.2, R23.2, TP5.1, U4.2 (VIN)
/CON_LED_CLK: J2.3, Q2.3 (D), R9.2
/CON_LED_DATA: J2.2, Q1.3 (D), R4.2
/CURR_SENS: R14.2, U1.5 (SENSOR_VP), U2.1
/DTR: J1.4, Q5.2 (E), R10.2
/ESP_EN: C10.1, Q3.3 (C), R5.2, TP1.1, U1.9 (EN)
/ESP_LED_CLK: Q2.2 (S), R8.2, U1.38 (IO19)
/ESP_LED_DATA: Q1.2 (S), R3.2, U1.42 (IO21)
/IO0: C9.1, Q5.3 (C), R6.2, TP2.1, U1.23 (IO0)
/LED_PWR: Q6.1 (G), R13.1, U1.39 (IO22)
/LNA_IN: C7.1, R7.2, U1.2 (LNA_IN)
/LNA_OUT: AE1.1 (A), C8.1, R7.1
/RTS: J1.5, Q3.2 (E), R12.2
/UART_RX: J1.2, R1.1
/UART_TX: J1.3, R2.1
GND: C1.2, C2.2, C3.2, C4.2, C5.2, C6.2, C7.2, C8.2, C9.2, C10.2, C11.2, C12.2, C13.2, C14.2, C15.2, C17.2, C18.2, C19.2, C20.2, C21.2, C22.2, C23.2, C25.2, C26.2, C27.2, C28.2, C29.2, D1.2 (A), D2.3 (common), J1.6, J2.4, J3.2, Q6.2 (S), R13.2, R15.1, R17.2, R18.2, R20.2, TP6.1, U1.49 (GND), U2.4 (V-), U3.3 (GND), U4.7 (GND)
unnamed: C16.1, U4.1 (BOOT)
unnamed: C16.2, D1.1 (K), L2.1, U4.8 (PH)
unnamed: C23.1, U4.4 (SS)
unnamed: C24.1, C25.1, U4.6 (COMP)
unnamed: C24.2, R20.1
unnamed: D2.1 (A1), D2.2 (A2), J3.1, R21.2, R23.1
unnamed: J2.1, Q4.3 (D)
unnamed: LED1.1 (K), R15.2
unnamed: LED2.1 (K), R19.2
unnamed: Q3.1 (B), R10.1
unnamed: Q4.1 (G), Q6.3 (D), R11.2
unnamed: Q5.1 (B), R12.1
unnamed: R1.2, U1.41 (U0TXD)
unnamed: R2.2, U1.40 (U0RXD)
unnamed: R14.1, R22.1, U2.2 (-)
unnamed: R16.2, R18.1, U4.5 (VSENSE)
unnamed: R17.1, R21.1, U2.3 (+)
unnamed: R19.1, U1.13 (IO33)

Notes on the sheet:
Reset
5V to 3.3V 1A LDO
LED Connector
Boot
12V to 5V 3A Buck
ESP AutoReset
LED Data Level Shifting
M3 Mounting Holes
UART Programming Header
Current Sense
12V 5A Input
ESP32 Pico D4

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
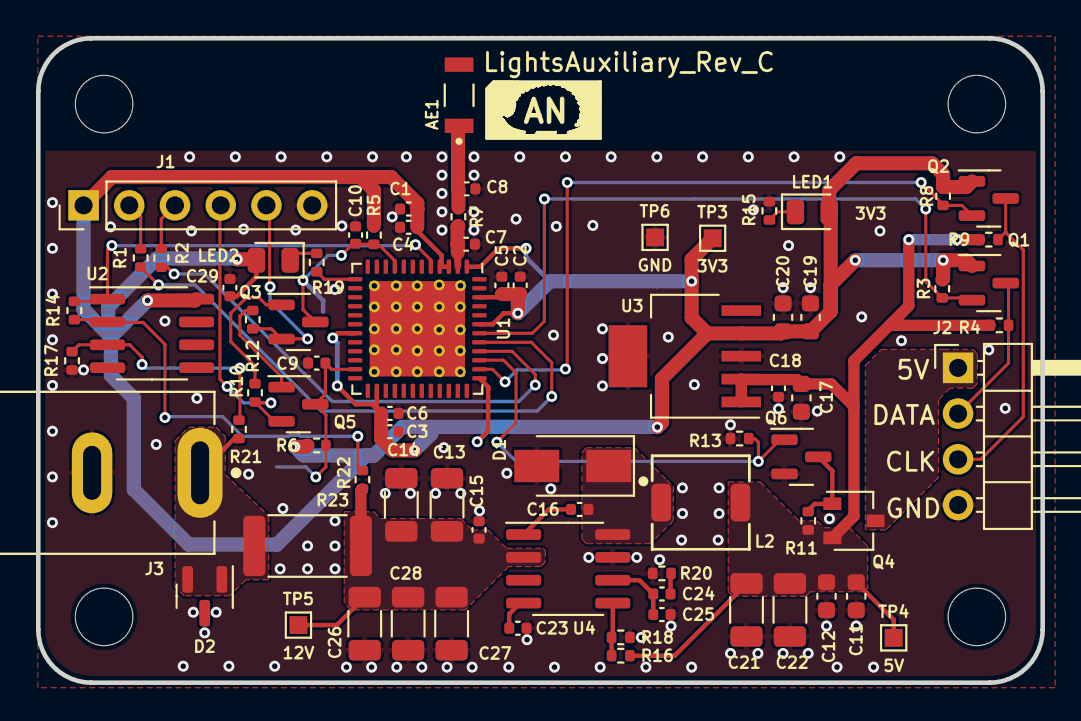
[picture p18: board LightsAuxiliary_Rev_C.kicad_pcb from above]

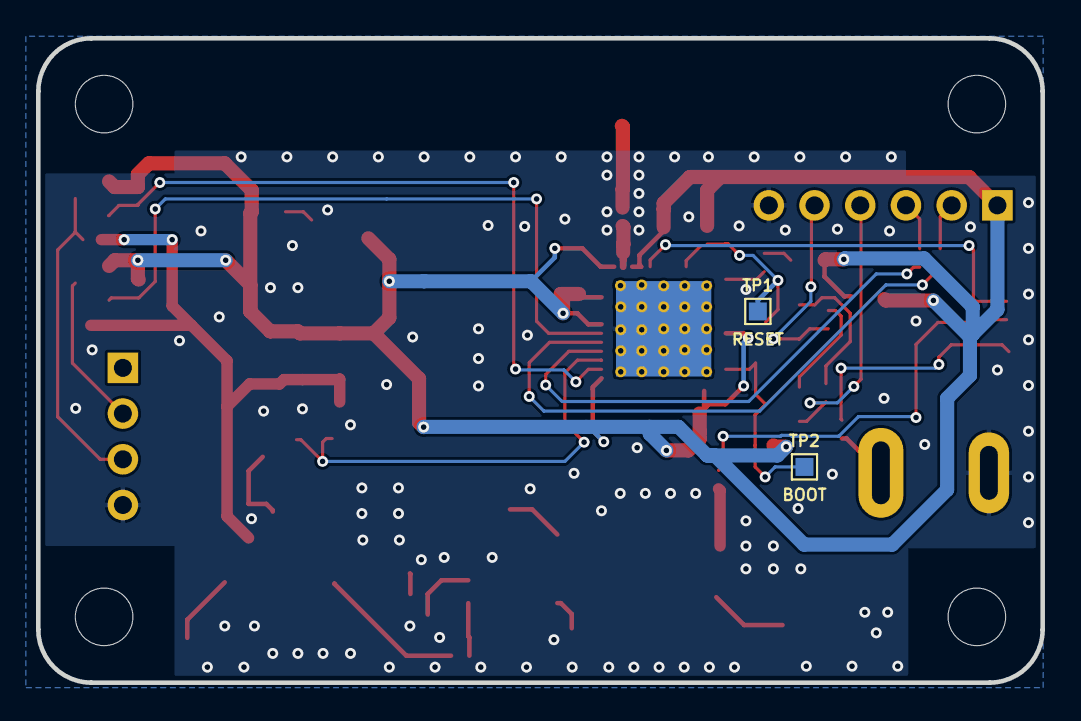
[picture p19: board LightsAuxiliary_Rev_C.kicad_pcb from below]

Board: 2 copper layers, 55.8 x 35.8 mm, 81 parts (2 on the bottom side), 36 nets.
